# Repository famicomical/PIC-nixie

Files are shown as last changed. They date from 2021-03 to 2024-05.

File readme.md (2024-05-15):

# PIC-nixie #
Design of a simple yet accurate Nixie clock controlled by a single-chip MCU. 

Logic Board:
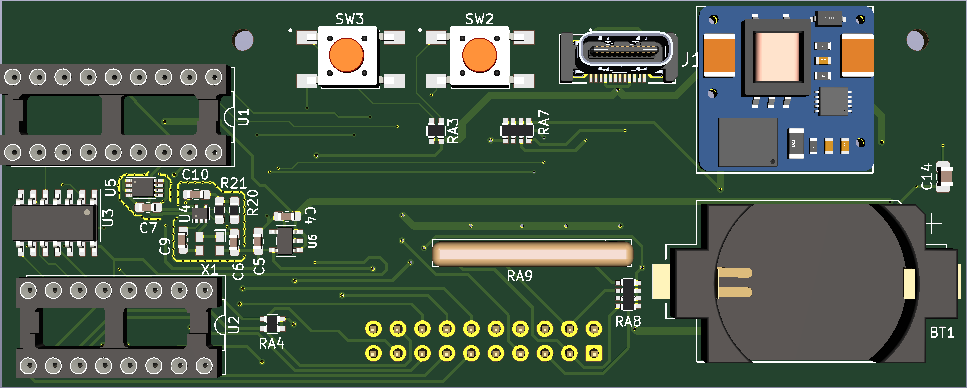
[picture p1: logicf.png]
Main PCB


Socket Board for IN-14 Tubes:
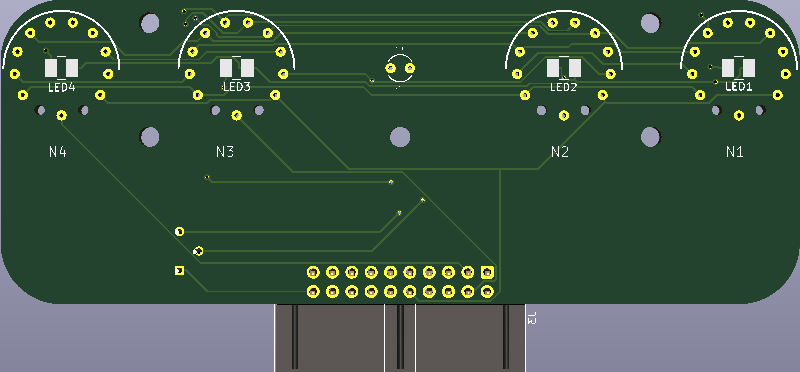
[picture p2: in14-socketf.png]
IN-14 Socket Board


The socket PCB plugs into the logic board to make an 'L' shape.

The time is displayed on four tubes with MUX-ed cathodes. The digits are output in binary-coded decimal for interfacing with the K155ID1 cathode driver. Anodes and the colon bulb (12:34) are also controlled by the PIC through BJT-pMOS level shifters.

The program tracks time such that the bottle-neck for clock accuracy will be the external oscillator. Anode blanking was implemented to ensure fast transitions on the Nixie tubes without ghosting (with help from a Zener diode). The clock will also run an outgassing routine every hour to prevent "cathode poisoning" and even out wear to lengthen tube life.

A CR2032 battery can be installed on the circuit board to provide backup power in the event of an outage. The tubes may go dark but the MCU will continue to run and keep time for about 11 hours until power is restored.

## Design

The PCB assembly is housed in a 'C'-shaped enclosure, which obscures the tops of the neon tubes. The design was developed in collaboration with my friend [Donald Swen](https://www.dswenn.com/projects/2019/11/27/22-Design.html) at Stanford's Design School. The idea is that, by hiding the pointed tops of the IN-14 tubes, the finished clock can achieve a symettry that would normally only be possible with IN-12 bulbs. With this clock shape, the vertical digits appear to be floating seamlessly within a cylinder. PIC-Nixie is the first neon tube clock to incorporate this aesthetic design principle.

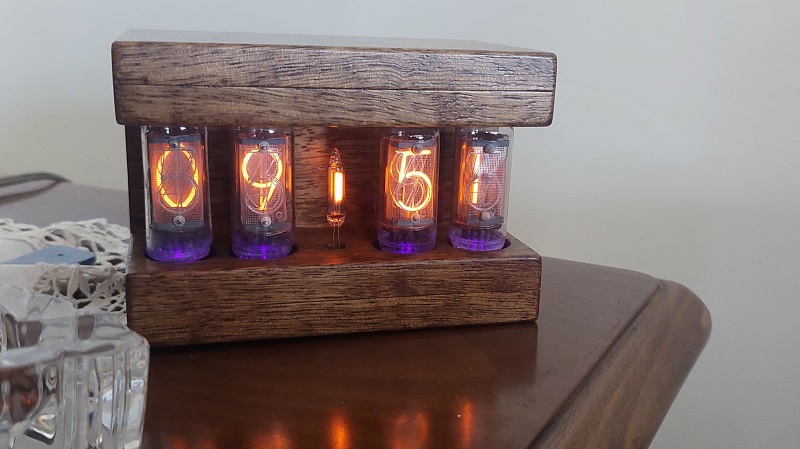
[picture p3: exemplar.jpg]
Serial #0


The enclosure for the prototype was made from stacked slabs of Fraké wood. The clock was a gift for my grandpa.

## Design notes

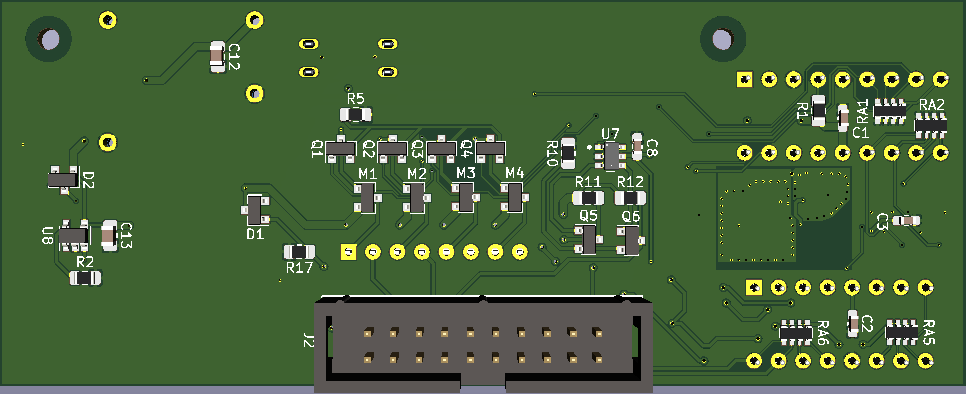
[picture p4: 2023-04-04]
logicb.png

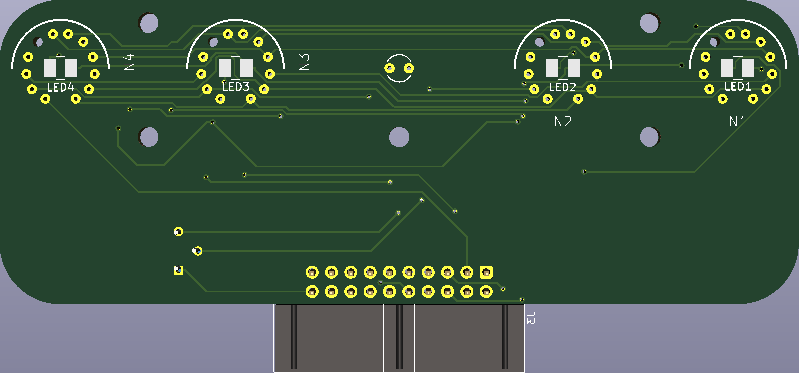
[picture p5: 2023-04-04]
in8-2-socketf.png

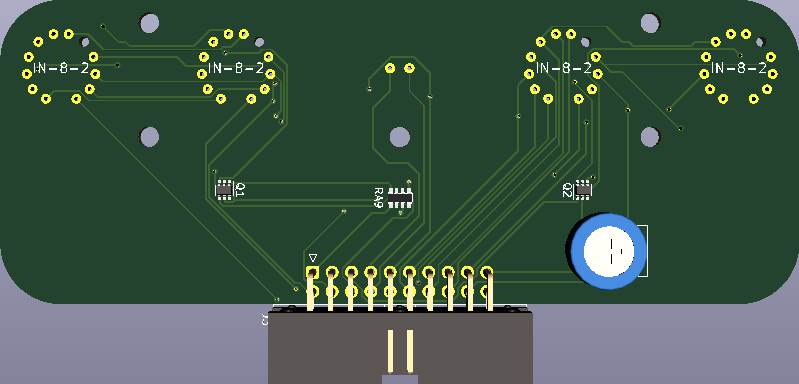
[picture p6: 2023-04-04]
in8-2-socketb.png

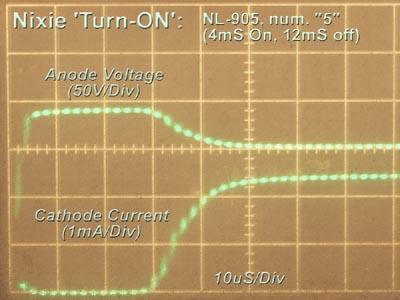
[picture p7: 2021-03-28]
docs/nixie related/timing01.jpg

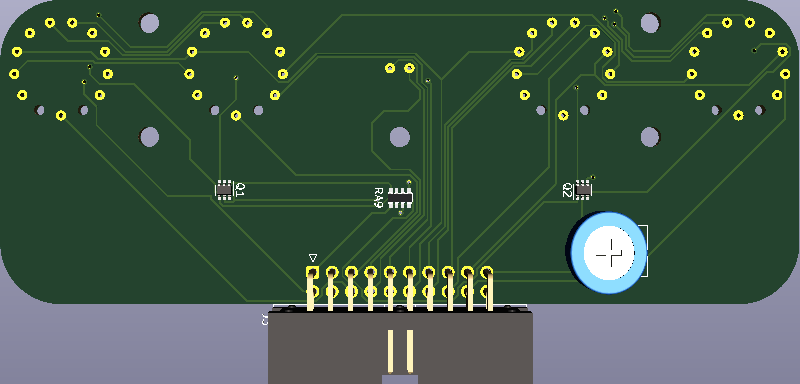
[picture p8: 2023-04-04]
in14-socketb.png

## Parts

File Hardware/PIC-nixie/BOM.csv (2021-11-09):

Item | Reference(s) | Value | Footprint | digikey part number | Qty
1 | C1, C2, C3, C7, C8 | 0.1u | SM0603 | 1276-1941-2-ND | 5
2 | C4, C5 | 1u | SM0603 | 445-12539-2-ND | 2
3 | C6, C10 | 0.01u NP0 | SM0603 | 478-3700-2-ND | 2
4 | C9 | 470p NP0 | SM0603 | 478-5777-2-ND | 1
5 | C11 | 2.2u film | external:QXK2E225KTP | 493-3523-ND | 1
6 | C12 | 2.2u | SM0805 | 1276-2953-2-ND | 1
7 | D1 | BZX84C68 | SOT-23 | BZX84C68LT1GOSTR-ND | 1
8 | J1 | DX07S024WJ3R400 | external:DX07S024WJ3R400 | 670-2950-2-ND | 1
9 | J2 | Conn_01x20_Female | Connector_IDC:IDC-Header_2x10_P2.54mm_Vertical | S9197-ND | 1
10 | M1, M2, M3, M4 | TP5335 | SOT-23 | TP5335K1-GTR-ND | 4
11 | PS1 | NCH8200HV | PIC-nixie:NCH8200HV | N/A | 1
12 | Q1, Q2, Q3, Q4, Q5, Q6 | PMBTA42,185 | SOT-23 | 1727-8537-2-ND | 6
13 | R1 | 10k | Resistor_SMD:R_0805_2012Metric_Pad1.15x1.40mm_HandSolder | 2019-SG73S2ATTD103JTR-ND | 1
14 | R5 | 5.1k | Resistor_SMD:R_0805_2012Metric_Pad1.15x1.40mm_HandSolder | P21099TR-ND | 1
15 | R10 | 2.2k | Resistor_SMD:R_0805_2012Metric_Pad1.15x1.40mm_HandSolder | 2019-SG73S2ATTD2201FTR-ND | 1
16 | R11, R12 | 120k | Resistor_SMD:R_0805_2012Metric_Pad1.15x1.40mm_HandSolder | 2019-RK73H2ARTTD1203FTR-ND | 2
17 | R17 | 220k | Resistor_SMD:R_0805_2012Metric_Pad1.15x1.40mm_HandSolder | A126350TR-ND | 1
18 | R20, R21 | 510k | Resistor_SMD:R_0603_1608Metric_Pad0.98x0.95mm_HandSolder | YAG4802TR-ND | 2
19 | RA1, RA2, RA7 | EXB-V8V103JV | Resistor_SMD:R_Array_Convex_4x0603 | Y4103TR-ND | 3
20 | RA3 | EXB-V8V821JV | Resistor_SMD:R_Array_Convex_4x0603 | Y4821TR-ND | 1
21 | RA4 | EXB-V4V105JV | Resistor_SMD:R_Array_Convex_2x0603 | Y2105TR-ND | 1
22 | RA5, RA6 | EXB-V8V105JV | Resistor_SMD:R_Array_Convex_4x0603 | Y4105TR-ND | 2
23 | RA8 | EXB-V8V224JV | Resistor_SMD:R_Array_Convex_4x0603 | Y4224TR-ND | 1
24 | RA9 | 4608X-102-822LF | Resistor_THT:R_Array_SIP8 | 4608X-2-822LF-ND | 1
25 | SW1, SW2, SW3 | SW_SPST | external:SW_TL3301SPF260QG | EG1870TR-ND | 3
26 | U1 | PIC16F54-IP | Package_DIP:DIP-18_W7.62mm_Socket | PIC16F54-I/P-ND, ED3318-ND | 1
27 | U2 | K155ID1 | Package_DIP:DIP-16_W7.62mm_Socket | N/A, ED90033-ND | 1
28 | U3 | 74HCT125D | external:74HCT125D | 1727-2834-2-ND | 1
29 | U4 | 74LVC1G04 | Package_TO_SOT_SMD:SOT-553 | 74LVC1G04Z-7DITR-ND | 1
30 | U5 | 74LVC2G80 | Package_SO:VSSOP-8_2.3x2mm_P0.5mm | 296-17083-2-ND | 1
31 | U6 | XC6221B302MR-G | external:XC6221B302MR-G | 893-1100-2-ND | 1
32 | U7 | 74HC2G14GV,125 | ext2:Nexperia-SOT457-11_2018-0-MFG | 1727-6046-1-ND | 1
33 | XTAL1 | I537-2O7-16.000, TG2520SMN 16 | PIC-nixie:Crystal_SMD_ILSI_I537-4Pin_3.2x2.5mm | 2780-I537-2O7-16.000MHZTR-ND | 1 | 732-TG252S16MCGNNM3

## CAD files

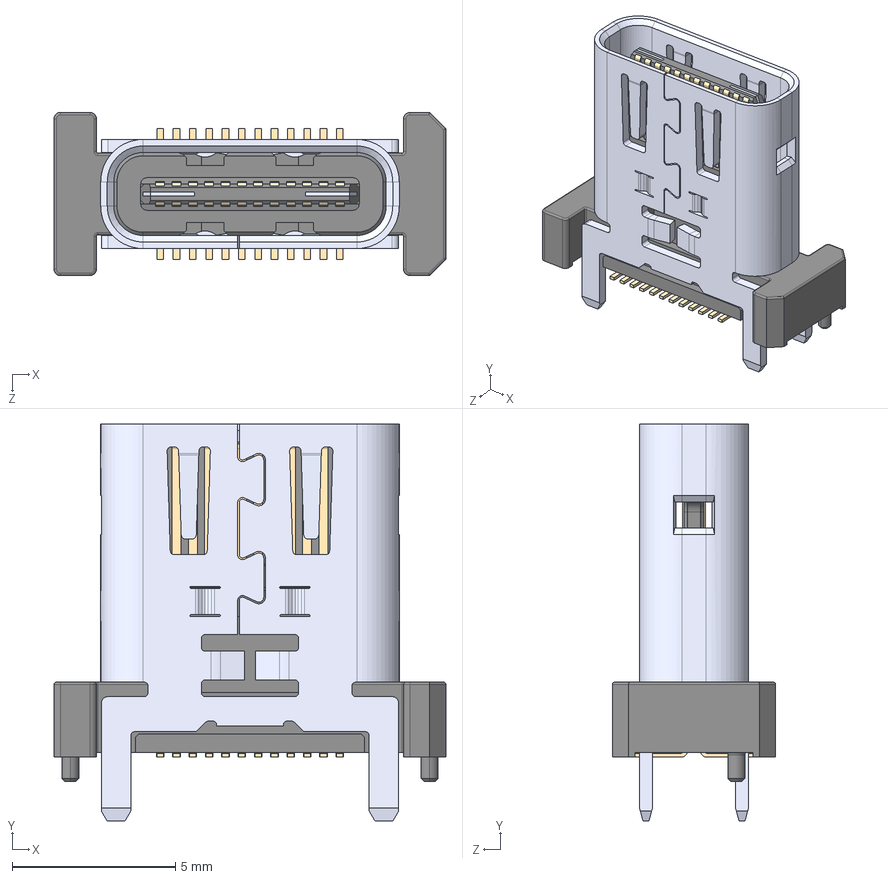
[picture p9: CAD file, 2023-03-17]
Hardware/PIC-nixie/DX07S024WJ3R400.STEP
12.0 x 12.2 x 5.00 mm

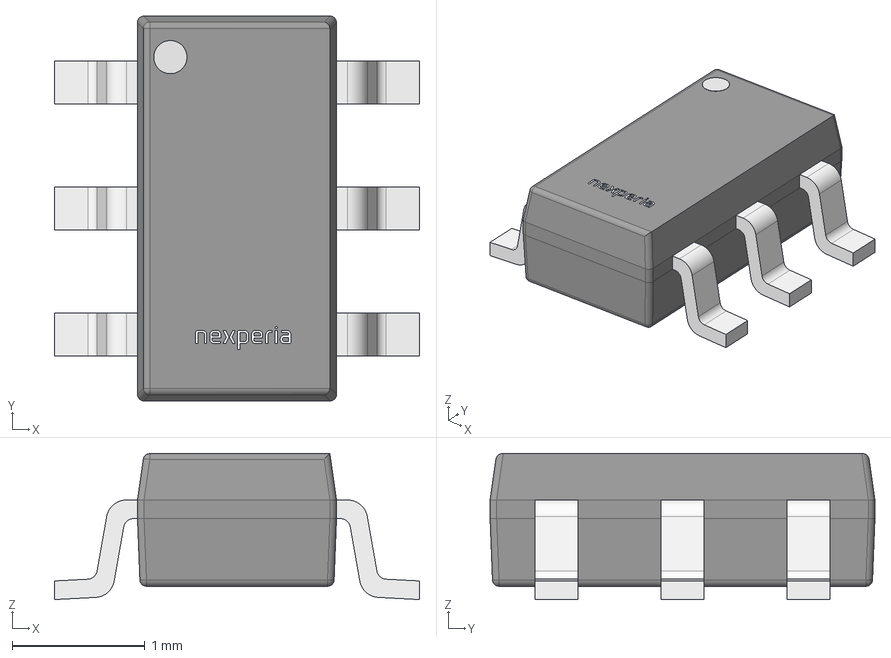
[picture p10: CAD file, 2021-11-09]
Hardware/PIC-nixie/eec.models/Nexperia_-_74HC2G14GV,125.step
2.75 x 2.90 x 1.10 mm
IC_BODY
IC_LEG x 6
circle
Nexperia

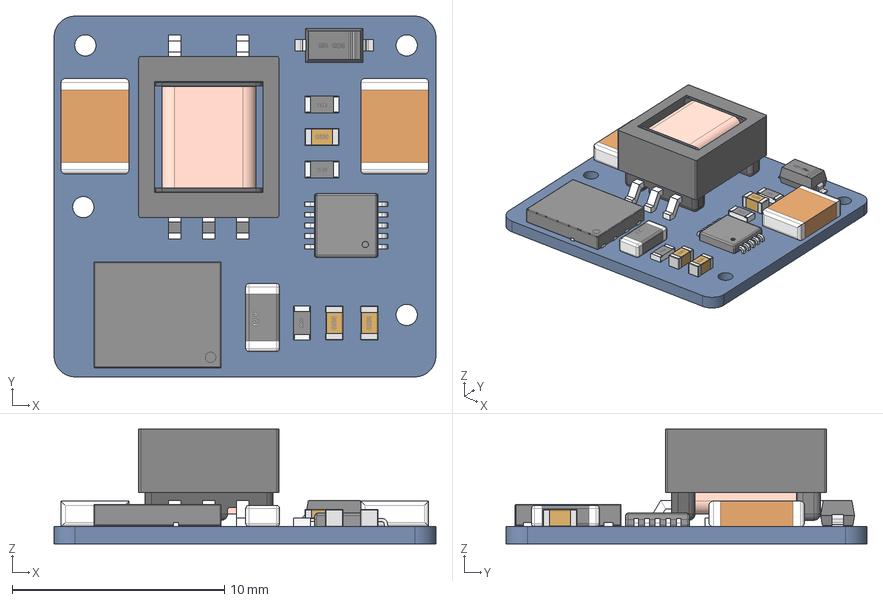
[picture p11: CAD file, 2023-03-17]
Hardware/PIC-nixie/NCH8200HV.step
18.0 x 17.0 x 5.42 mm
Board
SW3dPS-uMAX10_Part_141
SW3dPS-uMAX10_Part_2291
SW3dPS-uMAX10_Part_1911
SW3dPS-uMAX10_Part_1987
SW3dPS-uMAX10_Part_1492
SW3dPS-uMAX10_Part_2139
SW3dPS-uMAX10_Part_2443
SW3dPS-uMAX10_Part_1799
SW3dPS-uMAX10_Part_2367
SW3dPS-uMAX10_Part_2215
SW3dPS-uMAX10_Part_2063
TTRN-060S
R_0603 x 3
LOGO? x 6
1206R2
User_Library-SON8-5x6mm
SOD-123
LOGOﾔｲ｣ｭ｣ｰ.｣ｳ
1812C x 2
C_0603 x 3

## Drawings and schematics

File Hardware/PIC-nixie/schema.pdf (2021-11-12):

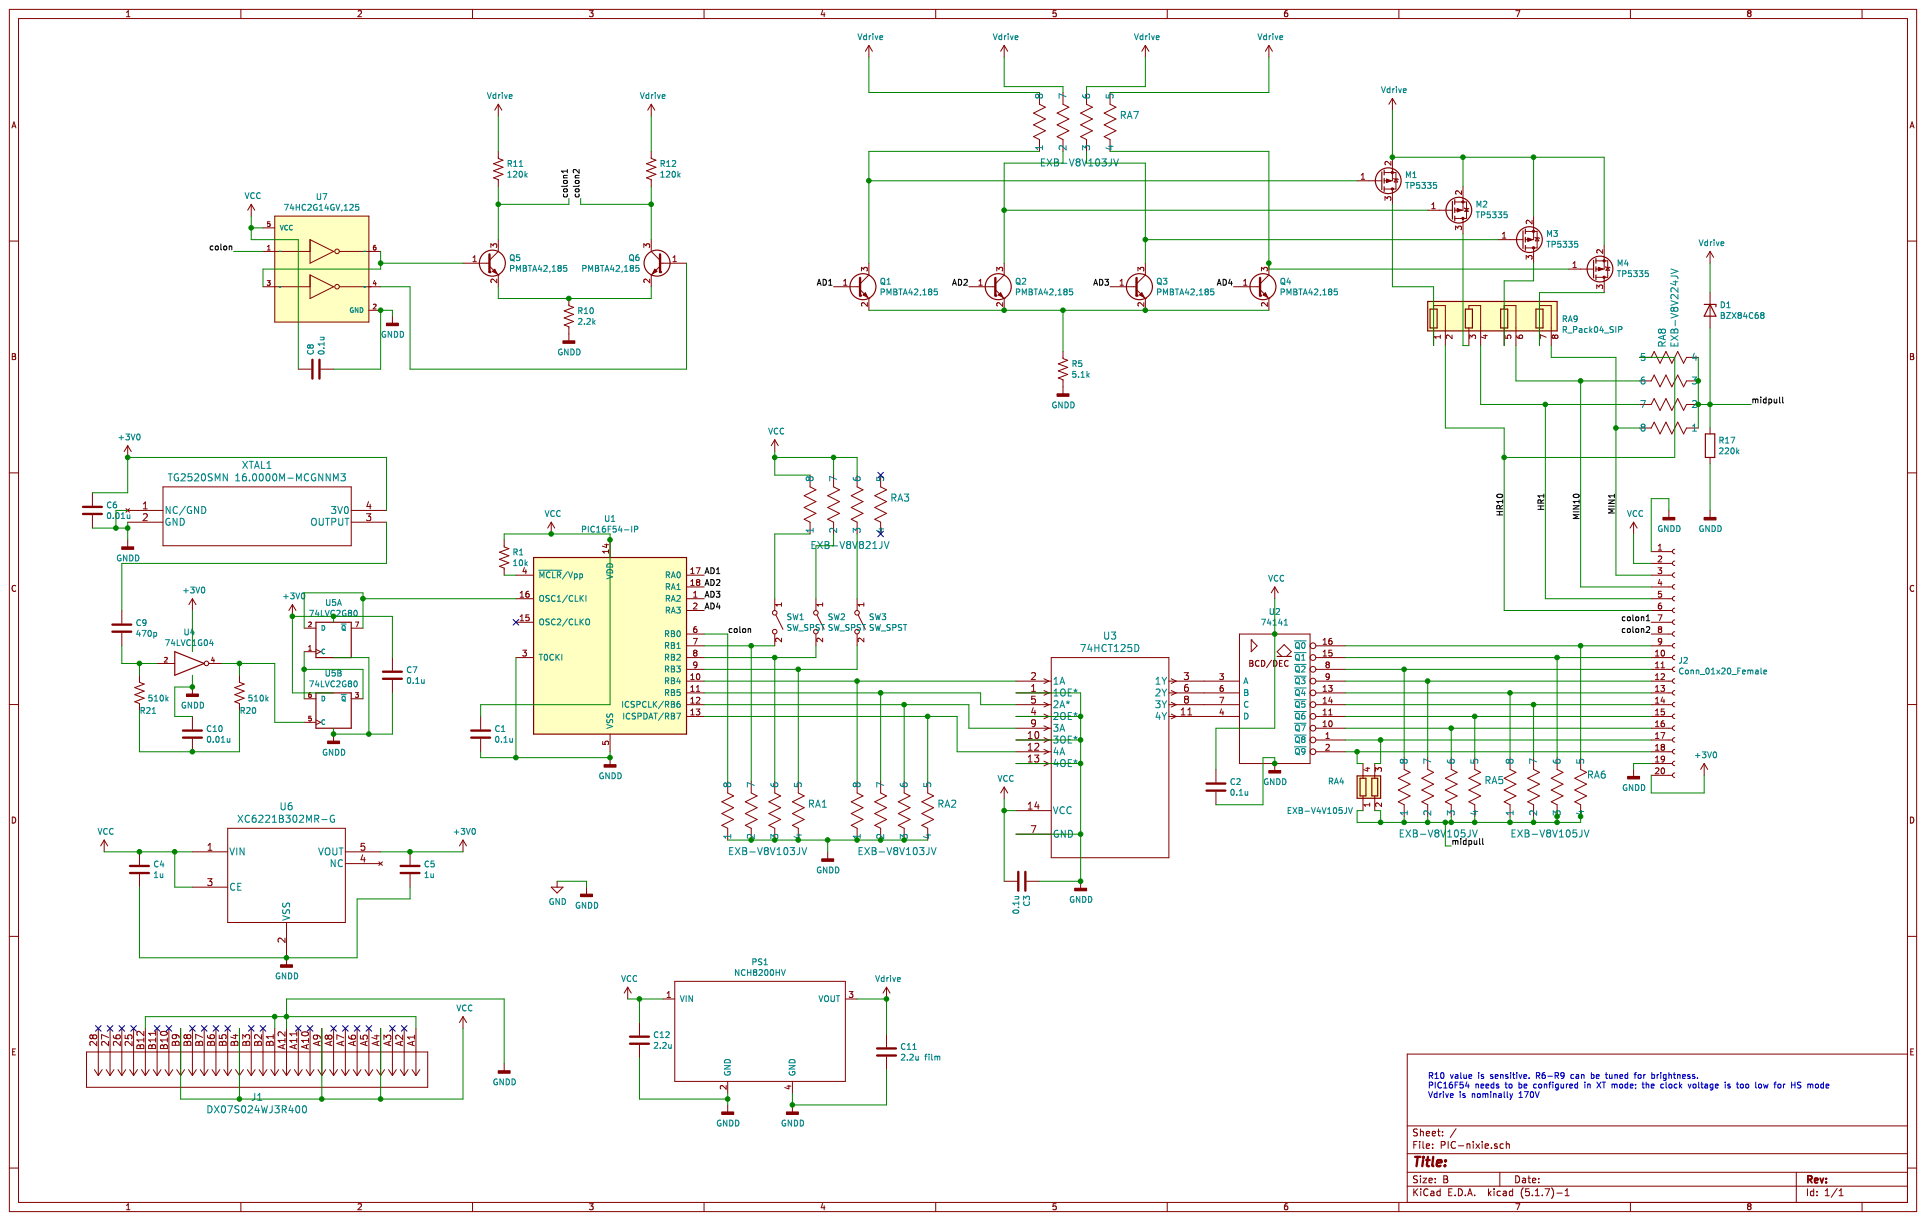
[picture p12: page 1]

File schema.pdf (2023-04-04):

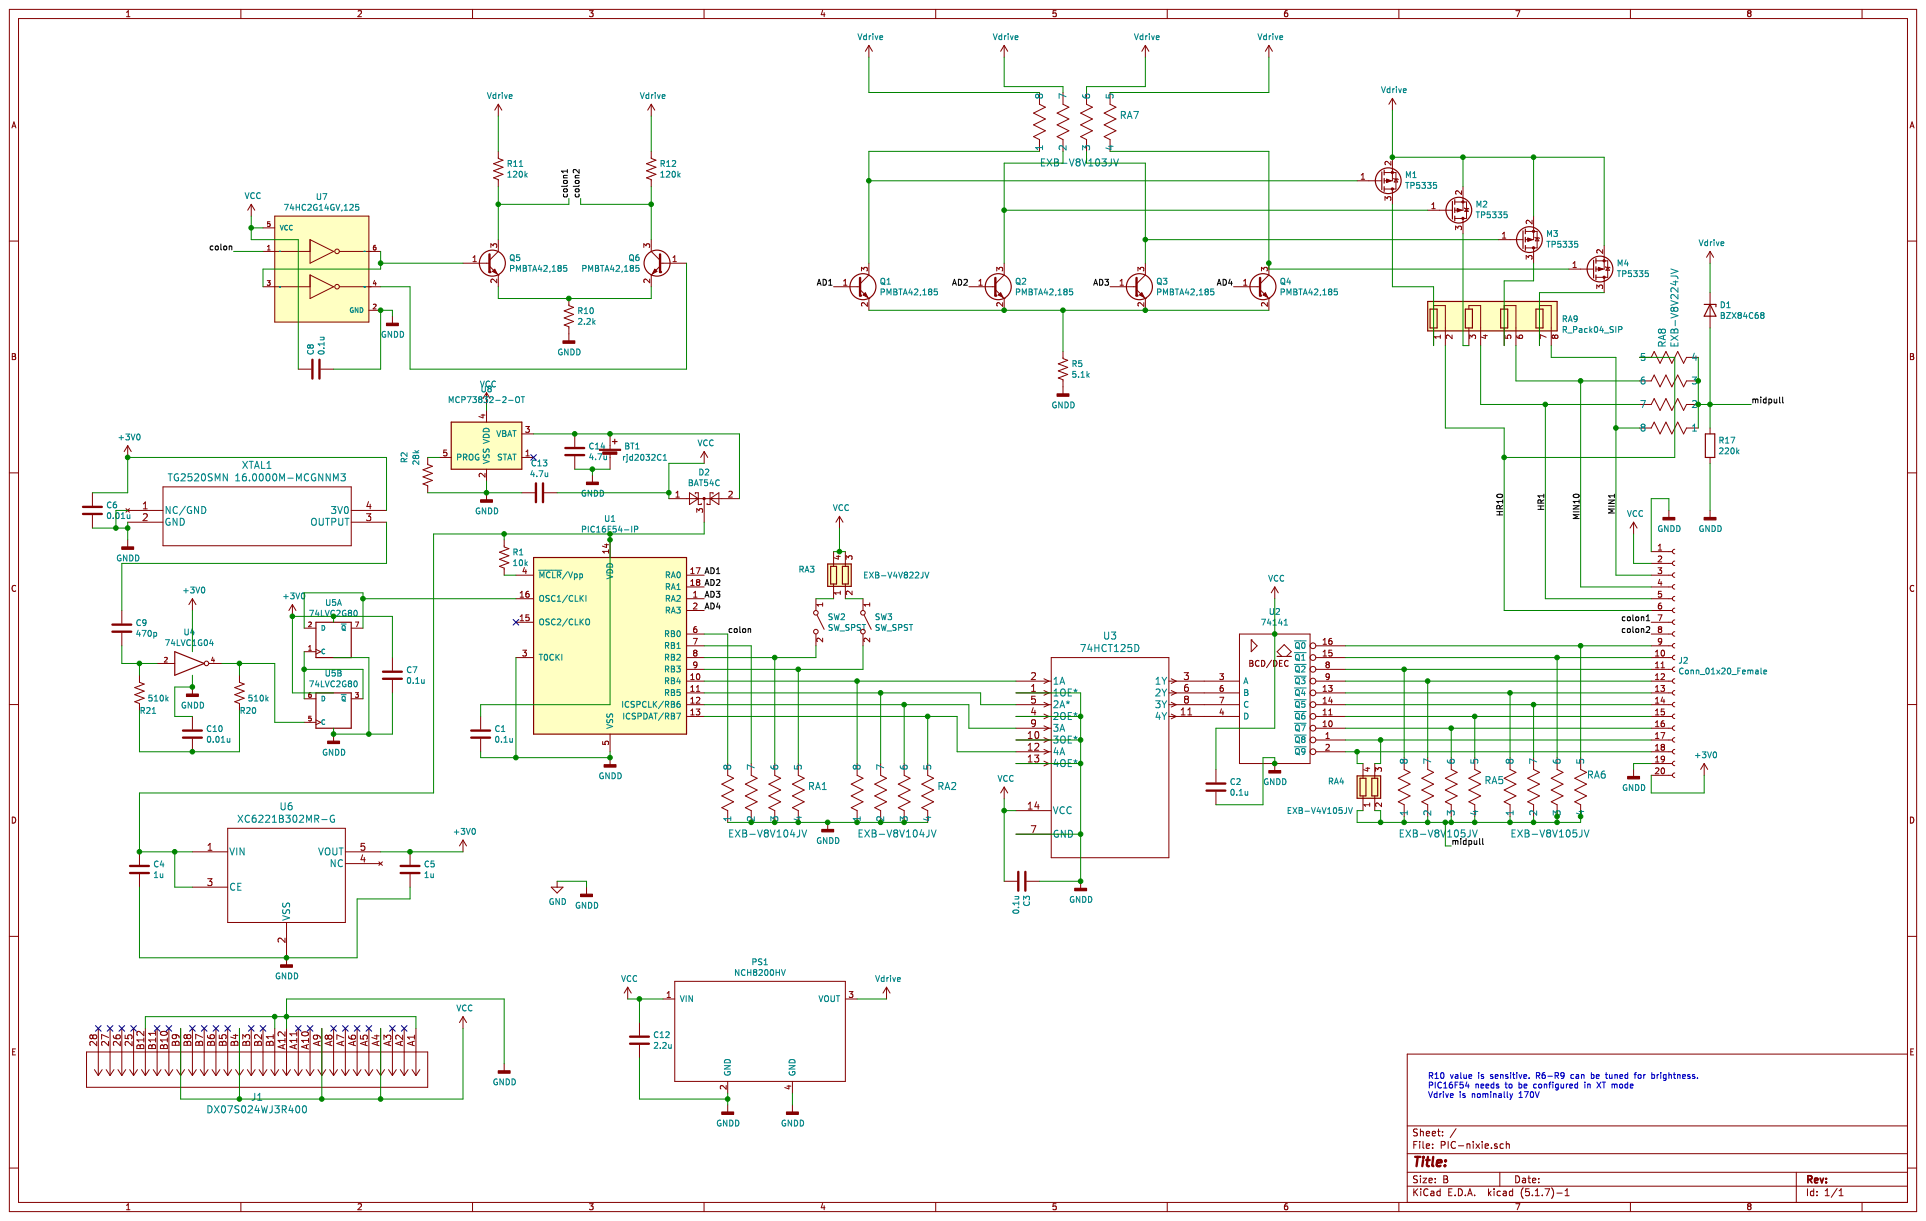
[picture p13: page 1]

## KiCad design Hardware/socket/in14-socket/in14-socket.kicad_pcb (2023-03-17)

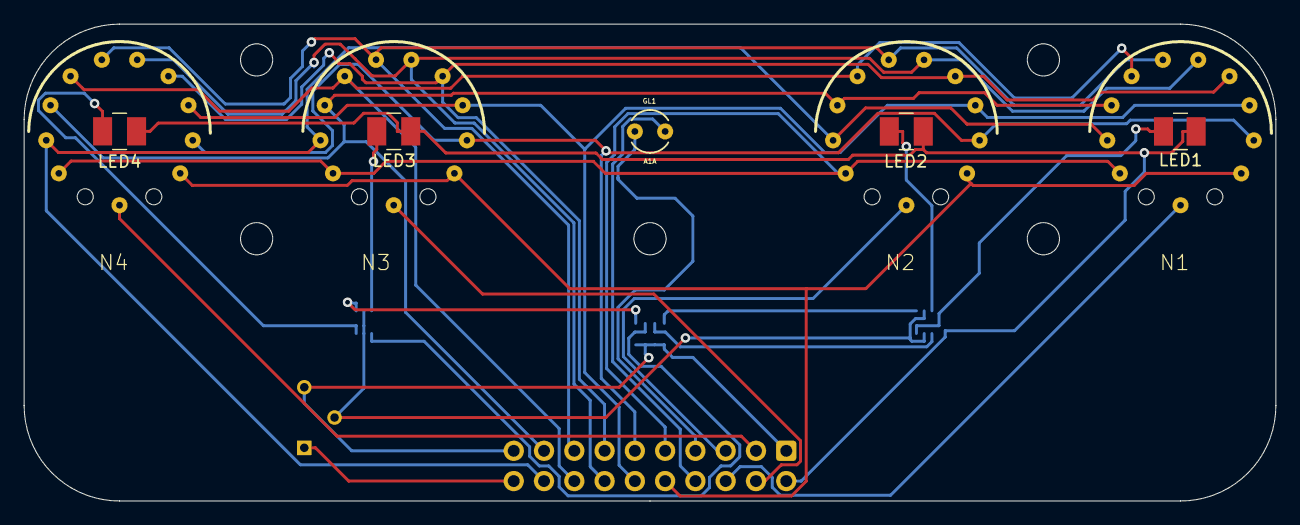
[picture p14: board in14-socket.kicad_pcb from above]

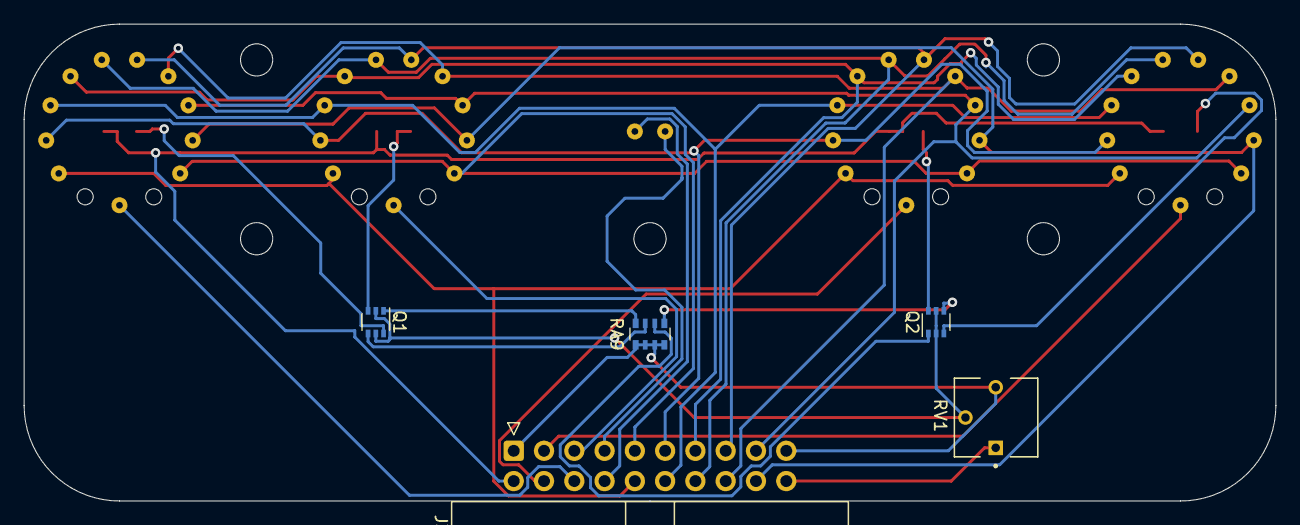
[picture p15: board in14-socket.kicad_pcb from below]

Board: 2 copper layers, 105.0 x 40.0 mm, 19 parts (5 on the bottom side), 28 nets.

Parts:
GL1: A1A; NE2-A1A
H1, H2, H3, H4, H5: MountingHole_2.7mm_M2.5
J3: Conn_01x20_Male; IDC-Header_2x10_P2.54mm_Horizontal
LED1, LED2, LED3, LED4: VLMU3100-GS08
N1, N2, N3, N4: Val**; IN-14
Q1, Q2: BC847BS; SOT-363_SC-70-6
RA9: 220 x 4; R_Array_Convex_4x0603
RV1: R_POT_TRIM_US; TRIM_3362P-1-302LF

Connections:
+3V0: J3.20, RV1.1
/HR1: J3.5, N2.A
/HR10: J3.6, N1.A
/MIN1: J3.3, N4.A
/MIN10: J3.4, N3.A
/colon1: GL1.1, J3.7
/colon2: GL1.2, J3.8
GND: J3.1, J3.19, RA9.1, RA9.2, RA9.3, RA9.4, RV1.3
unnamed: J3.9, N1.0, N2.0, N3.0, N4.0
unnamed: J3.10, N1.1, N2.1, N3.1, N4.1
unnamed: J3.11, N1.2, N2.2, N3.2, N4.2
unnamed: J3.12, N1.3, N2.3, N3.3, N4.3
unnamed: J3.13, N1.4, N2.4, N3.4, N4.4
unnamed: J3.14, N1.5, N2.5, N3.5, N4.5
unnamed: J3.15, N1.6, N2.6, N3.6, N4.6
unnamed: J3.16, N1.7, N2.7, N3.7, N4.7
unnamed: J3.17, N1.8, N2.8, N3.8, N4.8
unnamed: J3.18, N1.9, N2.9, N3.9, N4.9
unnamed: LED1.1, Q1.6
unnamed: LED2.1, Q1.3
unnamed: LED3.1, Q2.6
unnamed: LED4.1, Q2.3
unnamed: Q1.1, RA9.8
unnamed: Q1.2, Q1.5, Q2.2, Q2.5, RV1.2
unnamed: Q1.4, RA9.7
unnamed: Q2.1, RA9.6
unnamed: Q2.4, RA9.5
VCC: J3.2, LED1.2, LED2.2, LED3.2, LED4.2

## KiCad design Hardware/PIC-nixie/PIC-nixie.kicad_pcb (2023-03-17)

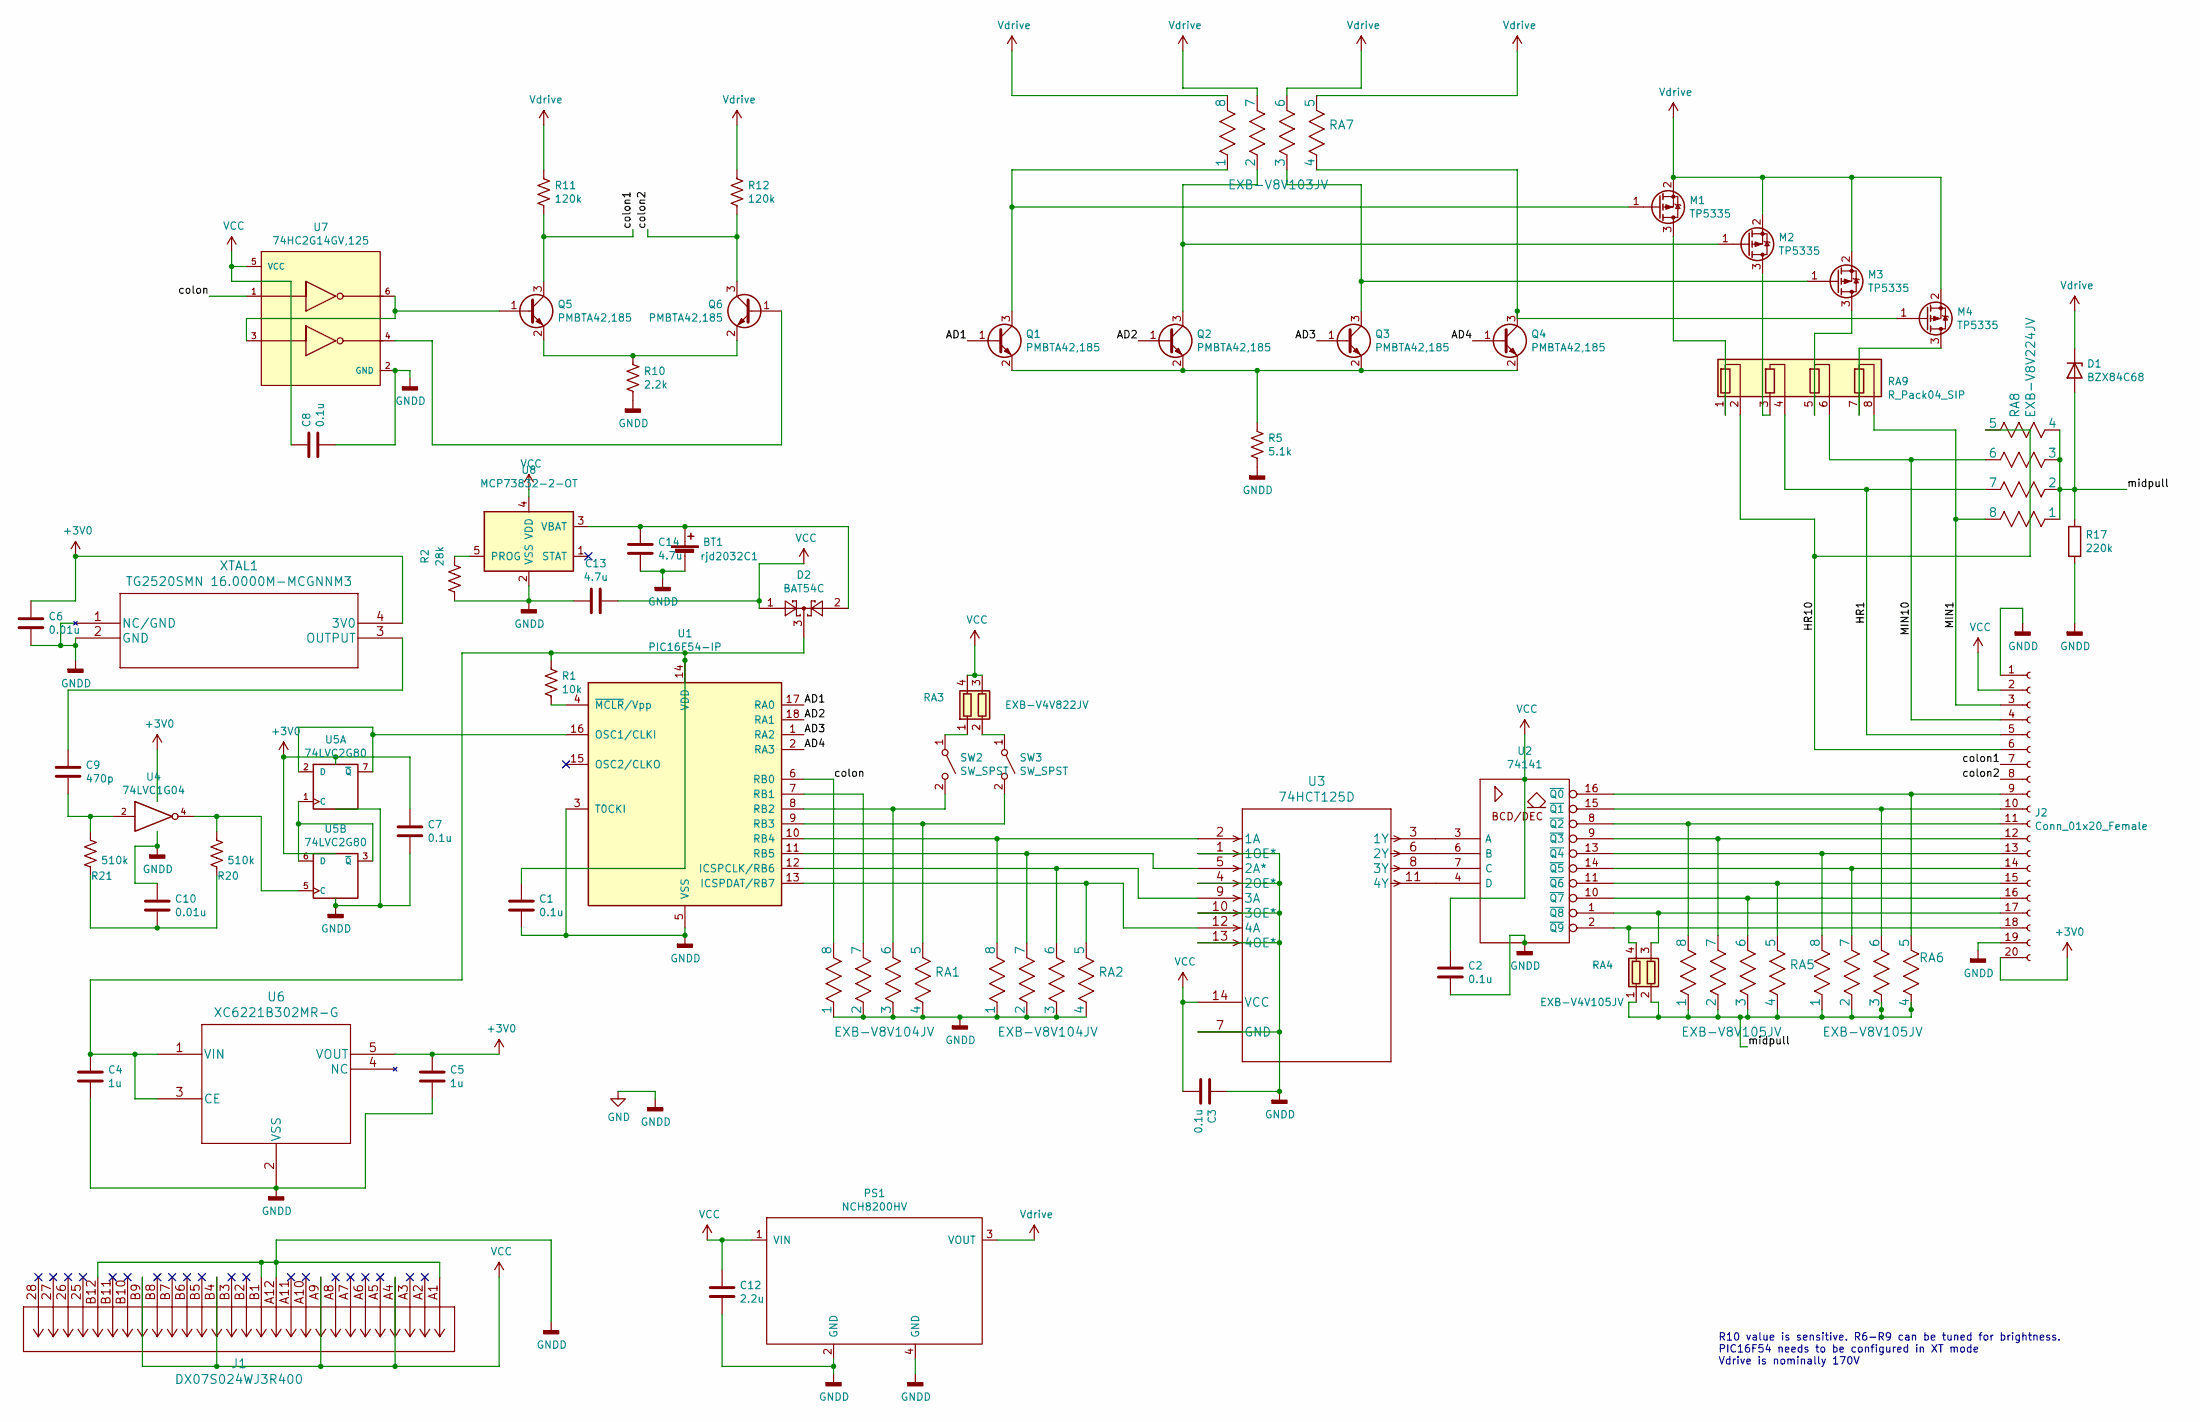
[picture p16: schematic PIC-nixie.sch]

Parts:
BT1: rjd2032C1; BatteryHolder_Keystone_1060_1x2032
C1, C2, C3, C7, C8: 0.1u; C_0603_1608Metric_Pad1.05x0.95mm_HandSolder
C4, C5: 1u; C_0603_1608Metric_Pad1.05x0.95mm_HandSolder
C6, C10: 0.01u; C_0603_1608Metric_Pad1.05x0.95mm_HandSolder
C9: 470p; C_0603_1608Metric_Pad1.05x0.95mm_HandSolder
C12: 2.2u; C_0805_2012Metric_Pad1.15x1.40mm_HandSolder
C13, C14: 4.7u; C_0805_2012Metric_Pad1.15x1.40mm_HandSolder
D1: BZX84C68; D_SOT-23_ANK
D2: BAT54C; SOT-23
J1: DX07S024WJ3R400; JAE_DX07S024WJ3R400
J2: Conn_01x20_Female; IDC-Header_2x10_P2.54mm_Vertical
M1, M2, M3, M4: TP5335; SOT-23
PS1: NCH8200HV
Q1, Q2, Q3, Q4, Q5, Q6: PMBTA42,185; SOT-23
R1: 10k; R_0805_2012Metric_Pad1.15x1.40mm_HandSolder
R2: 28k; R_0805_2012Metric_Pad1.15x1.40mm_HandSolder
R5: 5.1k; R_0805_2012Metric_Pad1.15x1.40mm_HandSolder
R10: 2.2k; R_0805_2012Metric_Pad1.15x1.40mm_HandSolder
R11, R12: 120k; R_0805_2012Metric_Pad1.15x1.40mm_HandSolder
R17: 220k; R_0805_2012Metric_Pad1.15x1.40mm_HandSolder
R20, R21: 510k; R_0603_1608Metric_Pad0.98x0.95mm_HandSolder
RA1, RA2: EXB-V8V104JV; R_Array_Convex_4x0603
RA3: EXB-V4V822JV; R_Array_Convex_2x0603
RA4: EXB-V4V105JV; R_Array_Convex_2x0603
RA5, RA6: EXB-V8V105JV; R_Array_Convex_4x0603
RA7: EXB-V8V103JV; R_Array_Convex_4x0603
RA8: EXB-V8V224JV; R_Array_Convex_4x0603
RA9: R_Pack04_SIP; R_Array_SIP8
SW2, SW3: SW_SPST; SW_TL3301SPF260QG
U1: PIC16F54-IP; DIP-18_W7.62mm_Socket
U2: 74141; DIP-16_W7.62mm_Socket
U3: 74HCT125D; SOIC-14_3.9x8.7mm_P1.27mm
U4: 74LVC1G04; SOT-553
U5: 74LVC2G80; VSSOP-8_2.3x2mm_P0.5mm
U6: XC6221B302MR-G
U7: 74HC2G14GV,125; Nexperia-SOT457-11_2018-0-MFG; mouser part number 771-HC2G14GV125; digikey description IC INVERTER SCHMITT 2CH 6TSOP
U8: MCP73832-2-OT; SOT-23-5
XTAL1: TG2520SMN 16.0000M-MCGNNM3

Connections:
+3V0: C5.1, C6.1, C7.1, J2.20, U4.5 (+V), U5.8 (+V), U6.5 (VOUT), XTAL1.4 (3V0); also elsewhere on the board
/AD1: Q1.1 (B), U1.17 (RA0)
/AD2: Q2.1 (B), U1.18 (RA1)
/AD3: Q3.1 (B), U1.1 (RA2)
/AD4: Q4.1 (B), U1.2 (RA3)
/HR1: J2.5, RA8.7, RA9.4 (R2.2)
/HR10: J2.6, RA8.5, RA9.2 (R1.2)
/MIN1: J2.3, RA8.8, RA9.8 (R4.2)
/MIN10: J2.4, RA8.6, RA9.6 (R3.2)
/colon: RA1.8, U1.6 (RB0), U7.1 (1A)
/colon1: J2.7, Q5.3 (C), R11.2
/colon2: J2.8, Q6.3 (C), R12.2
/midpull: D1.2 (A), R17.1, RA4.1 (R1.1), RA4.2 (R2.1), RA5.1, RA5.2, RA5.3, RA5.4, RA6.1, RA6.2, RA6.3, RA6.4, RA8.1, RA8.2, RA8.3, RA8.4
GND: BT1.2 (-), C1.2, C2.2, C3.1, C4.2, C5.2, C6.2, C7.2, C8.2, C10.1, C12.2, C13.2, C14.2, J1.A1, J1.A12, J1.B1, J1.B12, J2.1, J2.19, PS1.2 (GND), PS1.4 (GND), R2.2, R5.2, R10.2, R17.2, RA1.1, RA1.2, RA1.3, RA1.4, RA2.1, RA2.2, RA2.3, RA2.4, U1.3 (T0CKI), U1.5 (VSS), U2.12 (GND), U3.1 (1OE*), U3.4 (2OE*), U3.7 (GND), U3.10 (3OE*), U3.13 (4OE*), U4.3 (GND), U5.4 (GND), U6.2 (VSS), U7.2 (GND), U8.2 (VSS), XTAL1.1 (NC/GND), XTAL1.2 (GND); also elsewhere on the board
unnamed: BT1.1 (+), C14.1, D2.2, U8.3 (VBAT)
unnamed: C1.1, C4.1, D2.3, R1.1, U1.14 (VDD), U6.1 (VIN), U6.3 (CE)
unnamed 16: C9.1, XTAL1.3 (OUTPUT); also elsewhere on the board
unnamed: C9.2, R21.1, U4.2
unnamed: C10.2, R20.2, R21.2
unnamed: J2.9, RA6.5, U2.16 (~Q0)
unnamed: J2.10, RA6.6, U2.15 (~Q1)
unnamed: J2.11, RA5.8, U2.8 (~Q2)
unnamed: J2.12, RA5.7, U2.9 (~Q3)
unnamed: J2.13, RA6.8, U2.13 (~Q4)
unnamed: J2.14, RA6.7, U2.14 (~Q5)
unnamed: J2.15, RA5.5, U2.11 (~Q6)
unnamed: J2.16, RA5.6, U2.10 (~Q7)
unnamed: J2.17, RA4.3 (R2.2), U2.1 (~Q8)
unnamed: J2.18, RA4.4 (R1.2), U2.2 (~Q9)
unnamed: M1.1 (G), Q1.3 (C), RA7.1
unnamed: M1.3 (D), RA9.1 (R1.1)
unnamed: M2.1 (G), Q2.3 (C), RA7.2
unnamed: M2.3 (D), RA9.3 (R2.1)
unnamed: M3.1 (G), Q3.3 (C), RA7.3
unnamed: M3.3 (D), RA9.5 (R3.1)
unnamed: M4.1 (G), Q4.3 (C), RA7.4
unnamed: M4.3 (D), RA9.7 (R4.1)
unnamed: Q1.2 (E), Q2.2 (E), Q3.2 (E), Q4.2 (E), R5.1
unnamed: Q5.1 (B), U7.3 (2A), U7.6 (1Y)
unnamed: Q5.2 (E), Q6.2 (E), R10.1
unnamed: Q6.1 (B), U7.4 (2Y)
unnamed: R1.2, U1.4 (~MCLR~/Vpp)
unnamed: R2.1, U8.5 (PROG)
unnamed: R20.1, U4.4, U5.5 (C)
unnamed: RA1.5, SW3.2 (B), U1.9 (RB3)
unnamed: RA1.6, SW2.2 (B), U1.8 (RB2)
unnamed: RA1.7, U1.7 (RB1)
unnamed: RA2.5, U1.13 (ICSPDAT/RB7), U3.12 (4A)
unnamed: RA2.6, U1.12 (ICSPCLK/RB6), U3.9 (3A)
unnamed: RA2.7, U1.11 (RB5), U3.5 (2A*)
unnamed: RA2.8, U1.10 (RB4), U3.2 (1A)
unnamed: RA3.1 (R1.1), SW2.1 (A)
unnamed: RA3.2 (R2.1), SW3.1 (A)
unnamed: U1.16 (OSC1/CLKI), U5.2 (D), U5.7 (~Q)
unnamed: U2.3 (A), U3.3 (1Y)
unnamed: U2.4 (D), U3.11 (4Y)
unnamed: U2.6 (B), U3.6 (2Y)
unnamed: U2.7 (C), U3.8 (3Y)
unnamed: U5.1 (C), U5.3 (~Q), U5.6 (D)
VCC: C2.1, C3.2, C8.1, C12.1, C13.1, D2.1, J1.A4, J1.A9, J1.B4, J1.B9, J2.2, PS1.1 (VIN), RA3.3 (R2.2), RA3.4 (R1.2), U2.5 (VCC), U3.14 (VCC), U7.5 (VCC), U8.4 (VDD)
Vdrive: D1.1 (K), M1.2 (S), M2.2 (S), M3.2 (S), M4.2 (S), PS1.3 (VOUT), R11.1, R12.1, RA7.5, RA7.6, RA7.7, RA7.8

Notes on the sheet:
R10 value is sensitive. R6-R9 can be tuned for brightness. PIC16F54 needs to be configured in XT mode Vdrive is nominally 170V

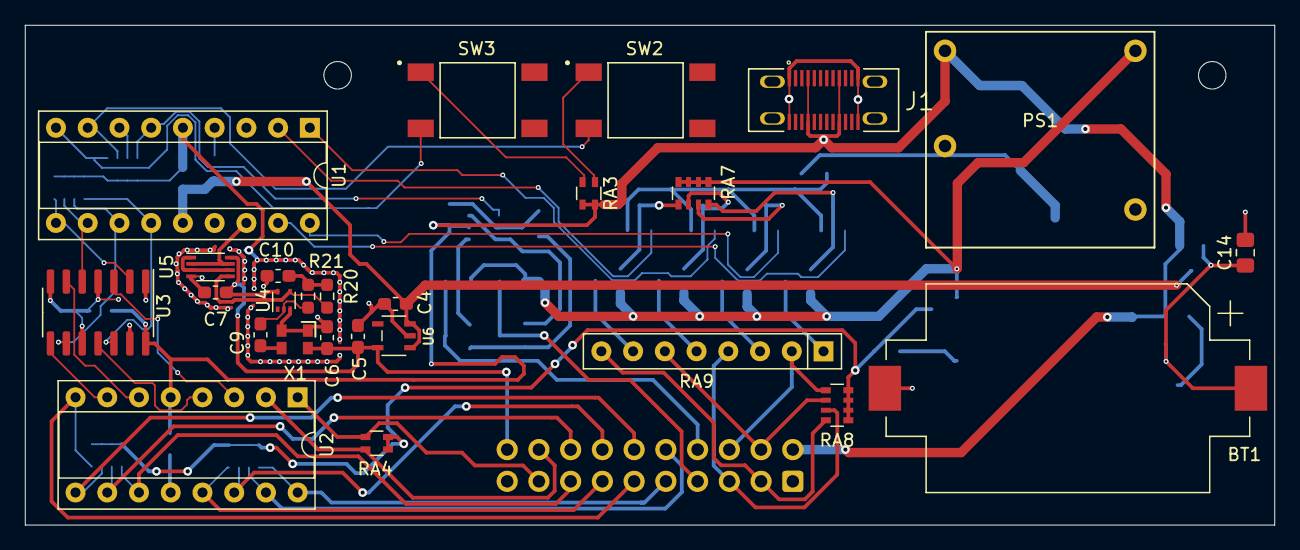
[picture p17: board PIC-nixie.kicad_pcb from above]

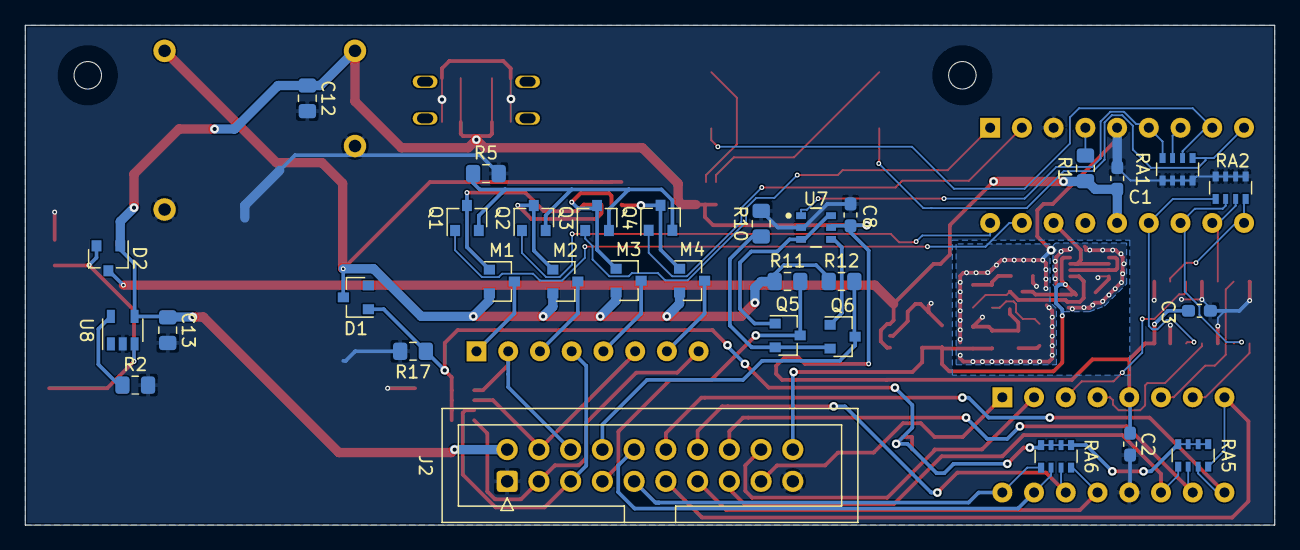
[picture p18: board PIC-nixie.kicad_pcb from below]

Board: 2 copper layers, 100.0 x 40.0 mm, 58 parts (32 on the bottom side), 61 nets.

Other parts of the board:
X1: TG2520SMN 16.0000M-MCGNNM3

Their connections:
+3V0: X1.4; also elsewhere on the board
GND: X1.1, X1.2; also elsewhere on the board
unnamed 16: X1.3; also elsewhere on the board

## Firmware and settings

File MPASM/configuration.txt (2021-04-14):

note:
use option __config 1 to set XT mode and turn off watchdog timer
use __config 2 to set HS oscillator config

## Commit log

2021-04-14 fully adapted pic code. assembles, but not debugged
    [configuration.txt]
2021-11-09 changed TCXO, PCB layout completed
    [BOM.csv, Nexperia_-_74HC2G14GV,125.step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]
2021-11-12 logic PCB tweaks, resize
    [PIC-nixie.kicad_pcb, in14-socket.sch]
2021-11-16 PCB as submitted to fab
    [PIC-nixie-B_Cu.gbl, PIC-nixie-B_Mask.gbs, PIC-nixie-B_Paste.gbp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]
2021-11-22 fix switch pin assignment, reduce hole size on nixie sockets
    [PIC-nixie.kicad_pcb, in14-socket.kicad_pcb, in8-2-socket.kicad_pcb]
2022-08-04 add battery backup for power failures
    [PIC-nixie.kicad_pcb, PIC-nixie.sch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]
2023-03-17 update 3D view, add figures
    [DX07S024WJ3R400.STEP, NCH8200HV.step, PIC-nixie.kicad_pcb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]
2023-03-17 relocate libraries for socket boards, fix routing & 3D models
    [in14-socket.kicad_pcb, in8-2-socket.kicad_pcb]
2023-03-17 fix routing on in-14 socket, make figures
    [in14-socket.kicad_pcb]

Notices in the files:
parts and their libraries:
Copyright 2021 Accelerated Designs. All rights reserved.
